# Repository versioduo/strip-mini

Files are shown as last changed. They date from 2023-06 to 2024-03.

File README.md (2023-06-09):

# strip-mini
🚦 LED strip hardware

## Board

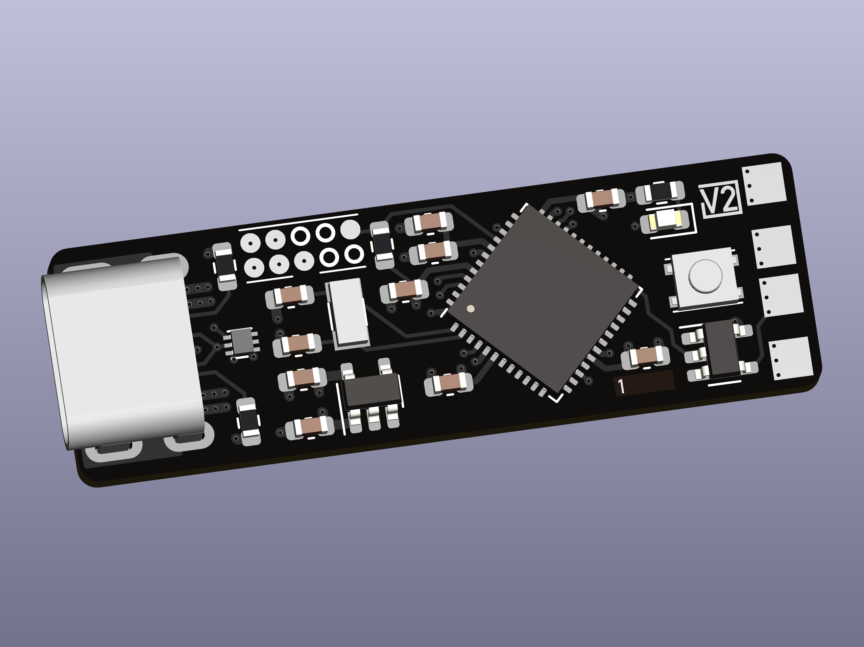
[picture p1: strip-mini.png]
board


## Video
[YouTube](https://www.youtube.com/watch?v=P1gKQrn-1O4)

## Schematic

[PDF](strip-mini.pdf)

## Bill Of Materials

[Interactive BOM](https://htmlpreview.github.io/?https://github.com/versioduo/strip-mini/main/strip-mini-bom.html)

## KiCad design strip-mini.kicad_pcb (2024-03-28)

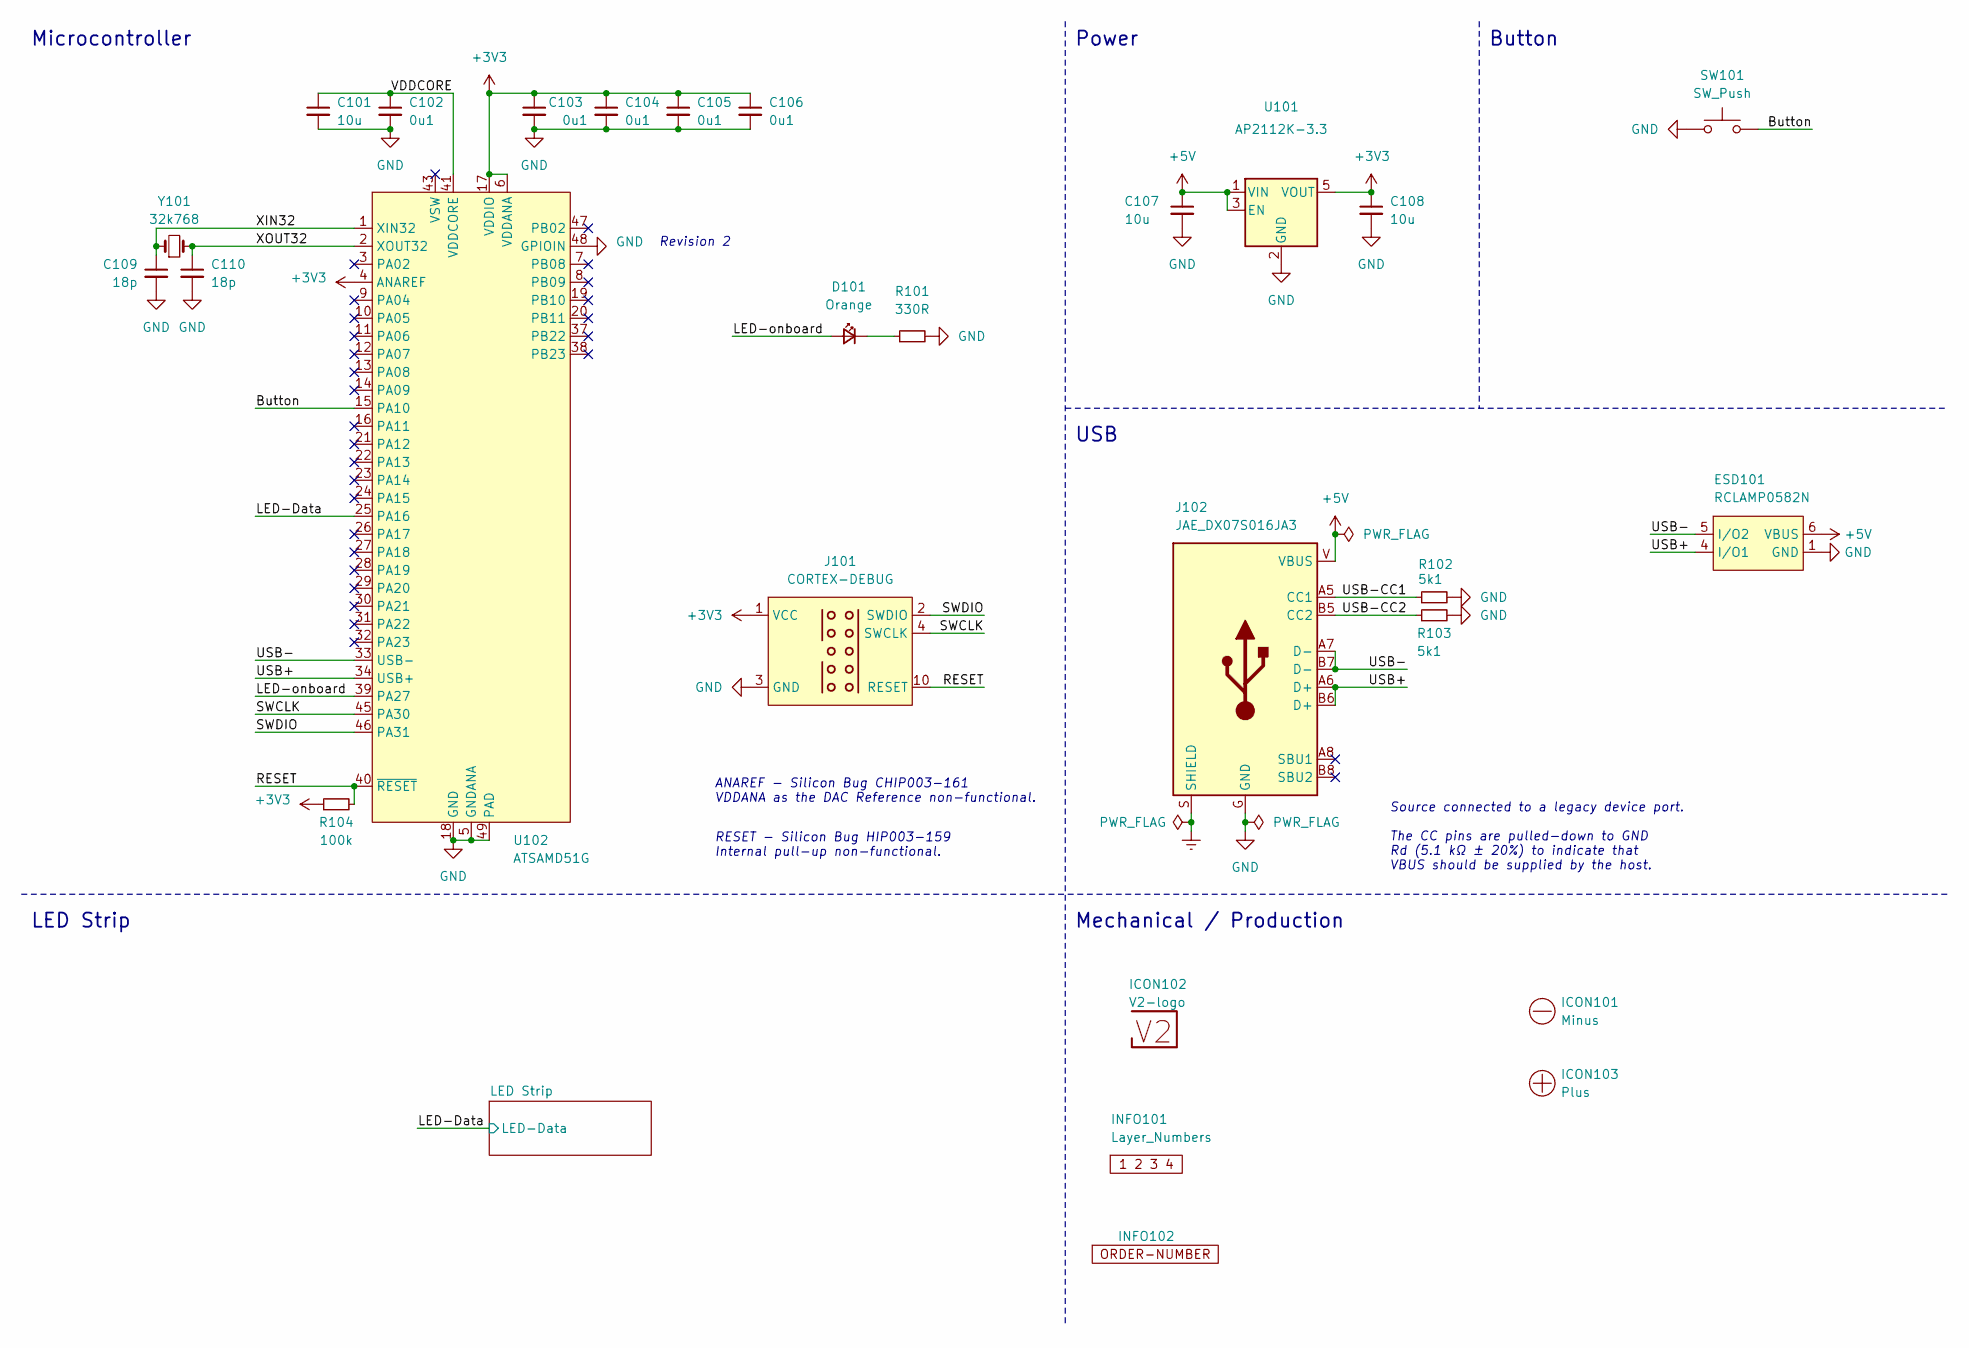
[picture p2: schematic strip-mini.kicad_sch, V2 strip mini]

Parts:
C101, C107, C108: 10u; C_0603_1608Metric
C102, C103, C104, C105, C106: 0u1; C_0603_1608Metric
C109, C110: 18p; C_0603_1608Metric
D101: Orange; LED_0603_1608Metric
ESD101: RCLAMP0582N; SLP1210N6
ICON101: Minus; Minus_Small
ICON102: V2-logo; Logo_Tiny
ICON103: Plus; Plus_Small
INFO101: Layer_Numbers
INFO102: ORDER-NUMBER; Order_Number
J101: CORTEX-DEBUG; Cortex_Debug_Pad
J102: JAE_DX07S016JA3
R101: 330R; R_0603_1608Metric
R102, R103: 5k1; R_0603_1608Metric
R104: 100k; R_0603_1608Metric
SW101: SW_Push; SKSG
U101: AP2112K-3.3; SOT-23-5
U102: ATSAMD51G; QFN-48-1EP_7x7mm_P0.5mm_EP5.45x5.45mm_ThermalVias
Y101: 32k768; Crystal_SMD_3215-2Pin_3.2x1.5mm

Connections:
+3V3: C103.1, C104.1, C105.1, C106.1, C108.1, J101.1 (VCC), R104.1, U101.5 (VOUT), U102.4 (ANAREF), U102.6 (VDDANA), U102.17 (VDDIO), U102.36 (VDDIO), U102.44 (VDDIO)
+5V: C107.1, ESD101.6 (VBUS), J102.V (VBUS), U101.1 (VIN), U101.3 (EN); also elsewhere on the board
/Button: SW101.2, U102.15 (PA10)
/LED-Data: U102.25 (PA16); also elsewhere on the board
/LED-onboard: D101.2 (A), U102.39 (PA27)
/RESET: J101.10 (RESET), R104.2, U102.40 (~RESET)
/SWCLK: J101.4 (SWCLK), U102.45 (PA30)
/SWDIO: J101.2 (SWDIO), U102.46 (PA31)
/USB+: ESD101.4 (I/O1), J102.A6 (D+), J102.B6 (D+), U102.34 (USB+)
/USB-: ESD101.5 (I/O2), J102.A7 (D-), J102.B7 (D-), U102.33 (USB-)
/USB-CC1: J102.A5 (CC1), R102.1
/USB-CC2: J102.B5 (CC2), R103.1
/VDDCORE: C101.1, C102.1, U102.41 (VDDCORE)
/XIN32: C109.1, U102.1 (XIN32), Y101.1
/XOUT32: C110.1, U102.2 (XOUT32), Y101.2
Earth: J102.S (SHIELD)
GND: C101.2, C102.2, C103.2, C104.2, C105.2, C106.2, C107.2, C108.2, C109.2, C110.2, ESD101.1 (GND), J101.3 (GND), J101.5 (GND), J102.G (GND), R101.2, R102.2, R103.2, SW101.1, U101.2 (GND), U102.5 (GNDANA), U102.18 (GND), U102.35 (GND), U102.42 (GND), U102.48 (GPIOIN), U102.49 (PAD); also elsewhere on the board
unnamed: D101.1 (K), R101.1

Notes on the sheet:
ANAREF -  Silicon Bug CHIP003-161 VDDANA as the DAC Reference non-functional.
RESET -  Silicon Bug HIP003-159 Internal pull-up non-functional.
 Source connected to a legacy device port. The CC pins are pulled-down to GND Rd (5.1 kΩ ± 20%) to indicate that VBUS should be supplied by the host.
Button
Revision 2
Power
Mechanical / Production
Microcontroller
USB
LED Strip

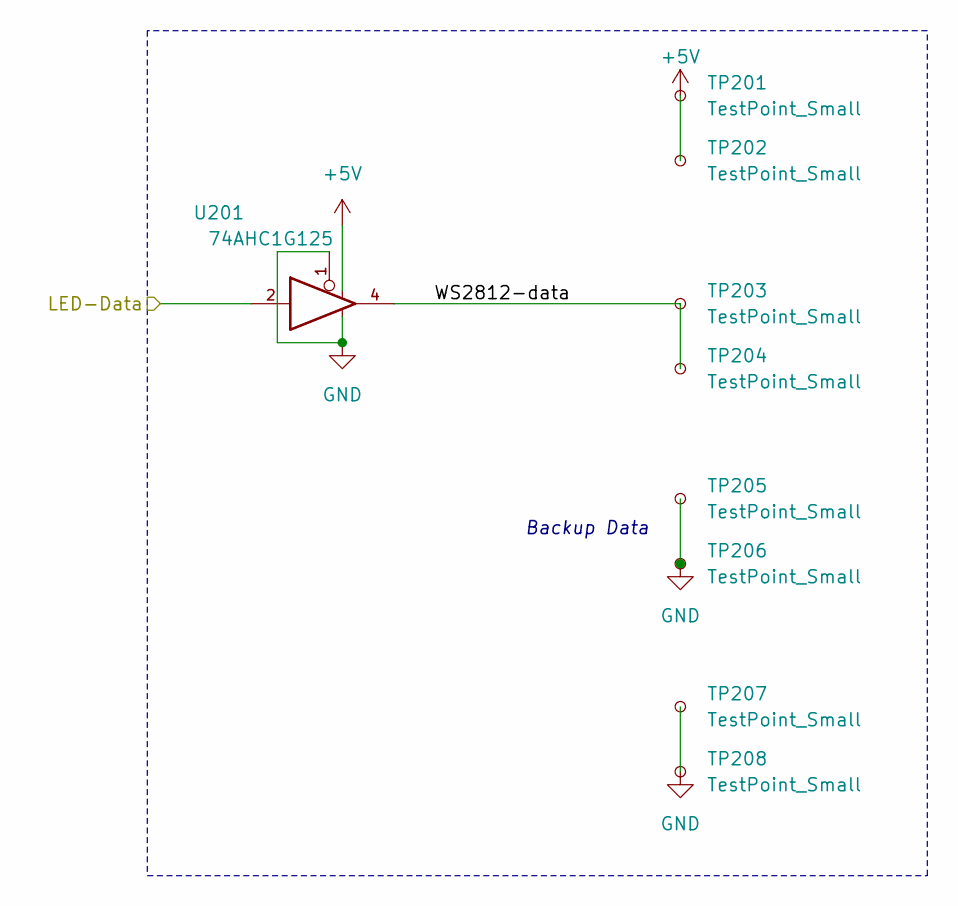
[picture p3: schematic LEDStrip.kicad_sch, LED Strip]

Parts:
TP201, TP202, TP203, TP204, TP205, TP206, TP207, TP208: TestPoint_Small; TestPoint_Pad_2.0x2.0mm
U201: 74AHC1G125; SOT-23-5

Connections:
+5V: TP201.1, TP202.1, U201.5; also elsewhere on the board
/LED Strip/WS2812-data: TP203.1, TP204.1, U201.4
/LED-Data: U201.2; also elsewhere on the board
GND: TP205.1, TP206.1, TP207.1, TP208.1, U201.1, U201.3; also elsewhere on the board

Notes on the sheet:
Backup Data

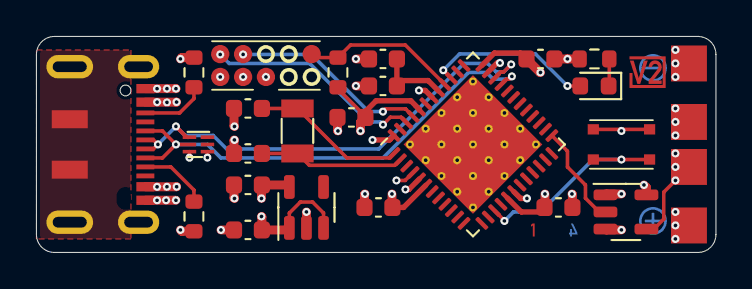
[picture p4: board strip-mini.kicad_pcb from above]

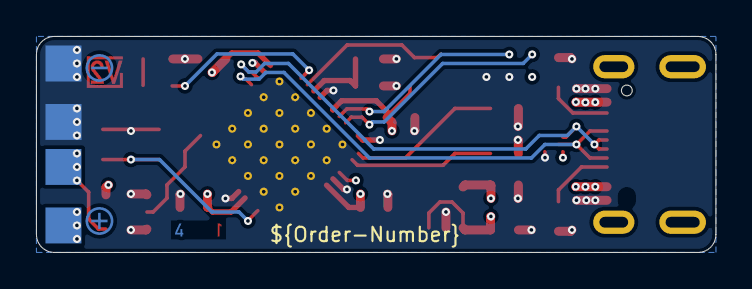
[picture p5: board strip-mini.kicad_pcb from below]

Board: 4 copper layers, 37.8 x 12.0 mm, 36 parts (7 on the bottom side), 18 nets.
